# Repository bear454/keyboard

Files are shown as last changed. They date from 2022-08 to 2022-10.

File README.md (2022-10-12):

# keyboard

_**Custom keycaps and layout for my [System76 Launch](https://system76.com/accessories/launch) keyboard**_

Special keys, in a pudding style, for my Launch. These include:

* Caps Lock
* Shift
* Ctrl/Cmd
* Meta/Super/Windows
* Menu
* Alt
* Compose
* Layer 2
* Layer 3
* Enter
* Del
* Bksp
* Home + Play/Pause
* PgUp + Vol Up
* PgDn + Vol Down
* End + Mute

For standard alphanumerics & function keys... just buy yourself some pudding caps. I recommend [LTC's XDA-profile Lava Caps](https://www.amazon.com/LTC-LavaCaps-Translucent-Mechanical-Keyboard/dp/B09J1HMJV9).

## Tools

Keycaps generated using [`openscad`](https://openscad.org/) and [rsheldiii/KeyV2](https://github.com/rsheldiii/KeyV2), then post-processed in [TinkerCAD](https://www.tinkercad.com/things/bIolghDg7ja-keycaps) and sliced in [PrusaSlicer](https://www.prusa3d.com/page/prusaslicer_424/).

Iconography from [Font Awesome 6 Pro](https://fontawesome.com/).

## The current state of things

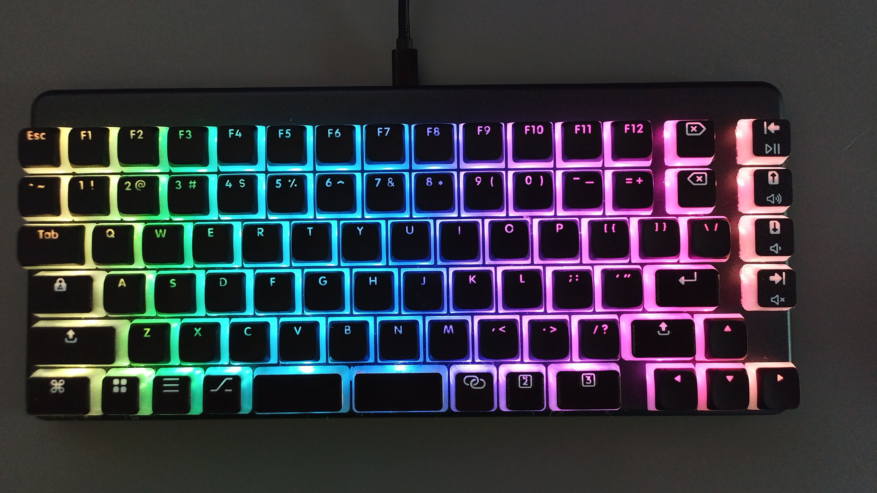
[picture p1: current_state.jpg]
current keyboard layout


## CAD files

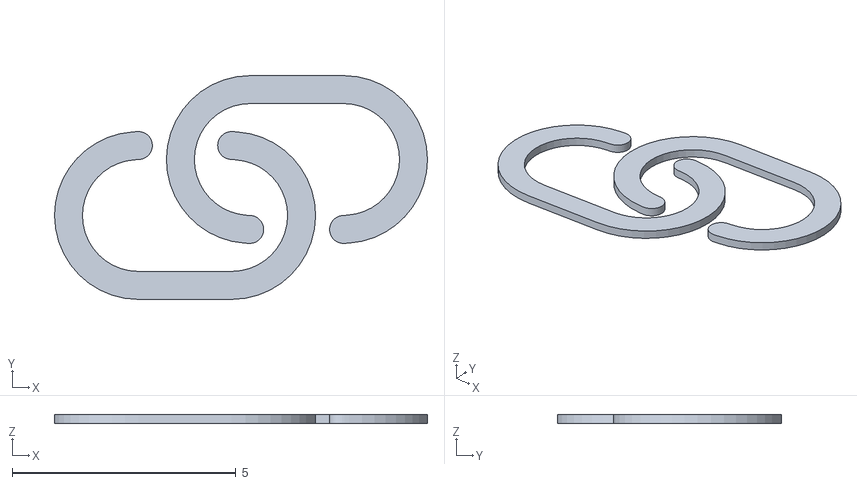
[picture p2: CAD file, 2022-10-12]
print/keycaps-compose-legend.stl
8.33 x 5.00 x 0.2

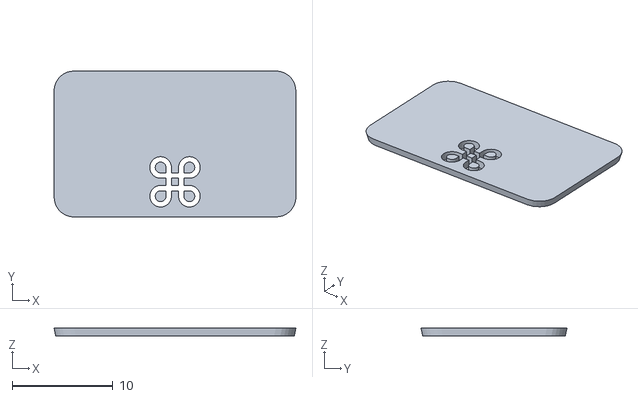
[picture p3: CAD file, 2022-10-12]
print/keycaps-ctrl_1.5u-face.stl
24.0 x 14.5 x 0.798

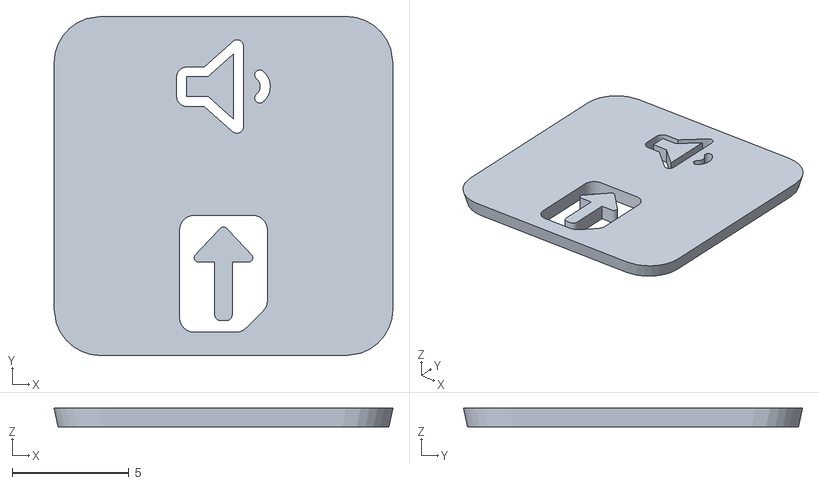
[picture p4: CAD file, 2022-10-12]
print/keycaps-pgdn-face.stl
14.5 x 14.5 x 0.798

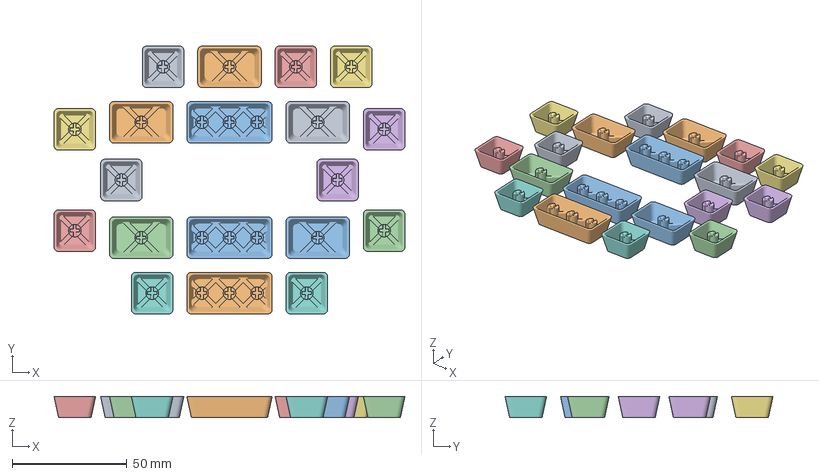
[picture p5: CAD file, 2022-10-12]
print/keycaps.3mf
152.9 x 116.8 x 9.30 mm
compose
caps_1.5u
shift_2u
ctrl_1.5u
window
menu
alt
l2
l3_1.5u
shift_1.5u
enter_1.5u
bksp
del
home
end
pgup
pgdn
space_2u

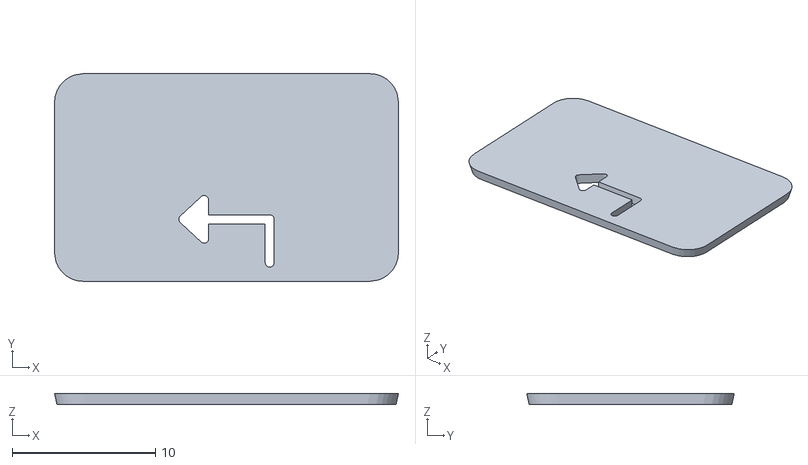
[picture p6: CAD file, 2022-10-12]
print/keycaps-enter_1.5u-face.stl
24.0 x 14.5 x 0.798

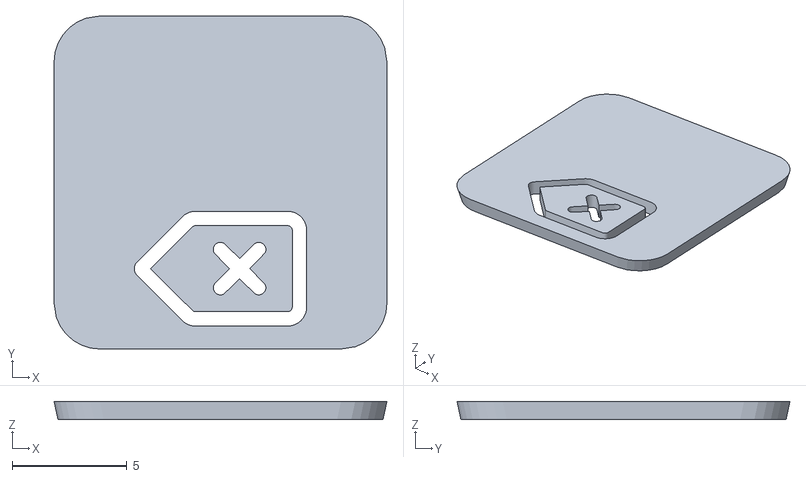
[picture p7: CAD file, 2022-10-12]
print/keycaps-bksp-face.stl
14.5 x 14.5 x 0.798

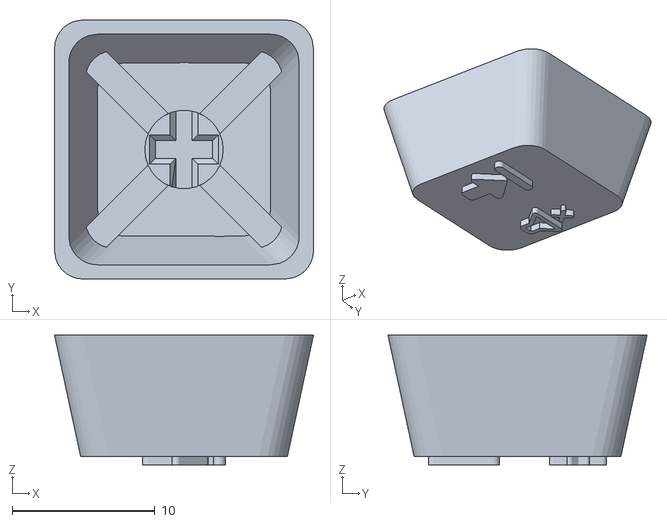
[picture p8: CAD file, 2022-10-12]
print/keycaps-end-body.stl
18.2 x 18.2 x 9.10

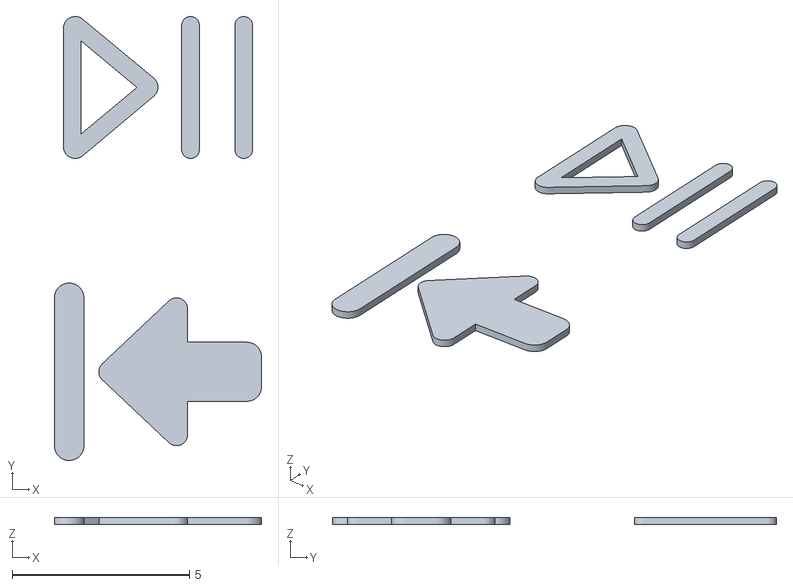
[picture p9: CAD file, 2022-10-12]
print/keycaps-home-legend.stl
5.84 x 12.5 x 0.2

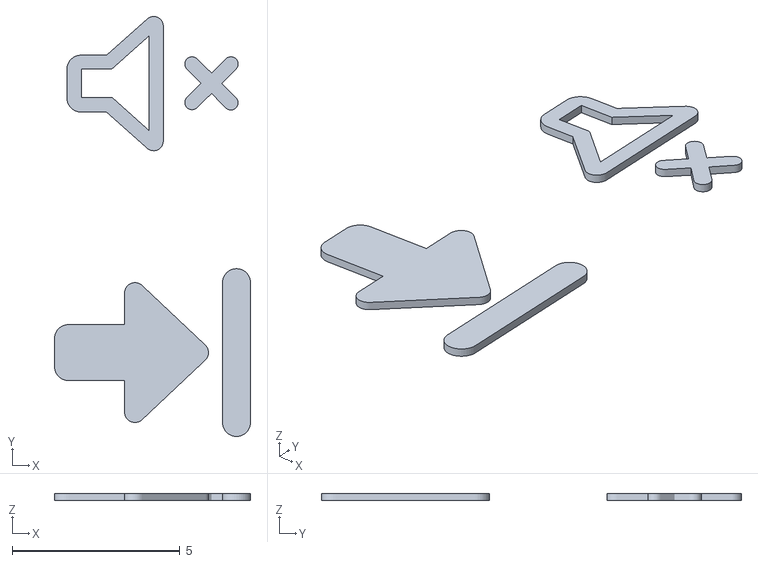
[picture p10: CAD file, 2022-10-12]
print/keycaps-end-legend.stl
5.84 x 12.5 x 0.2

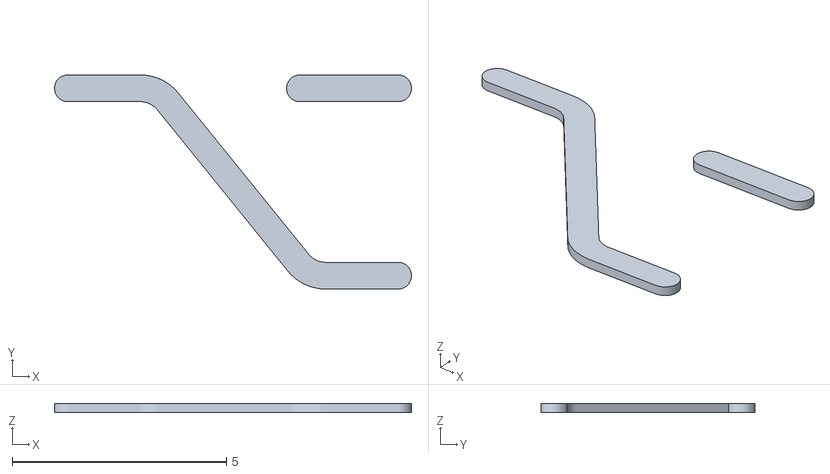
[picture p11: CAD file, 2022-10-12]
print/keycaps-alt-legend.stl
8.33 x 5.00 x 0.2

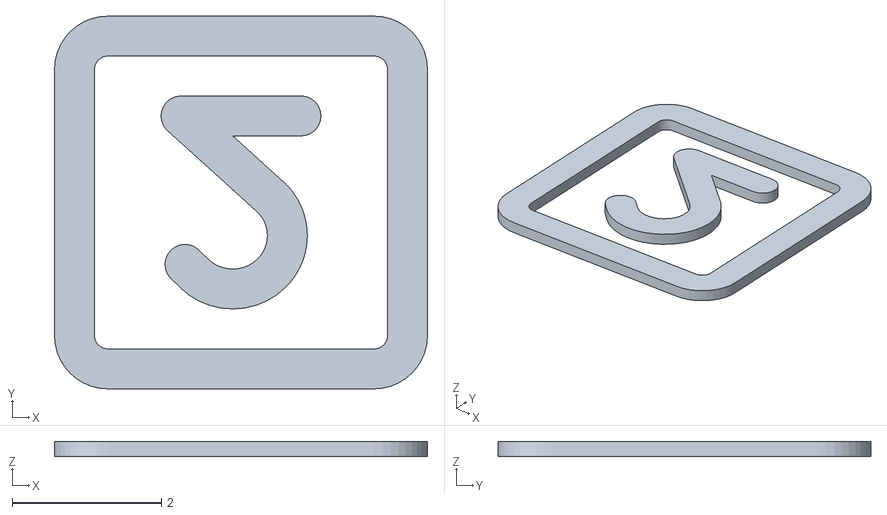
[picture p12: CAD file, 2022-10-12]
print/keycaps-l2-legend.stl
5.00 x 5.00 x 0.2

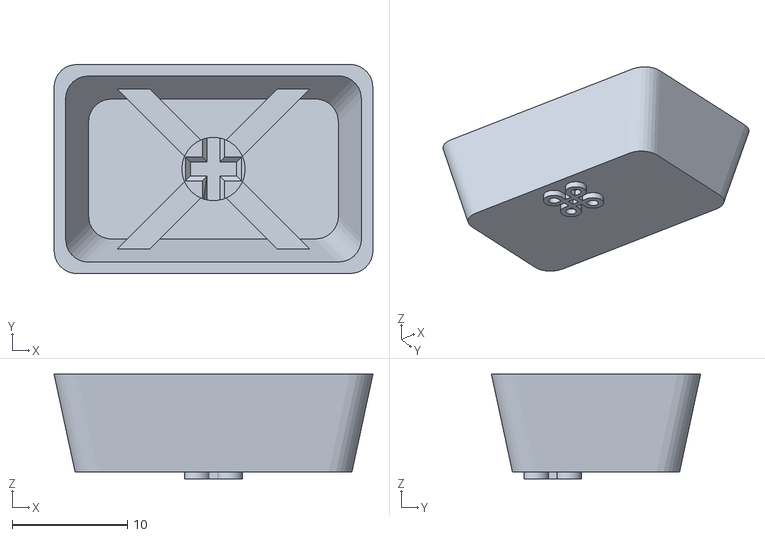
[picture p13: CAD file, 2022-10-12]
print/keycaps-ctrl_1.5u-body.stl
27.7 x 18.2 x 9.10

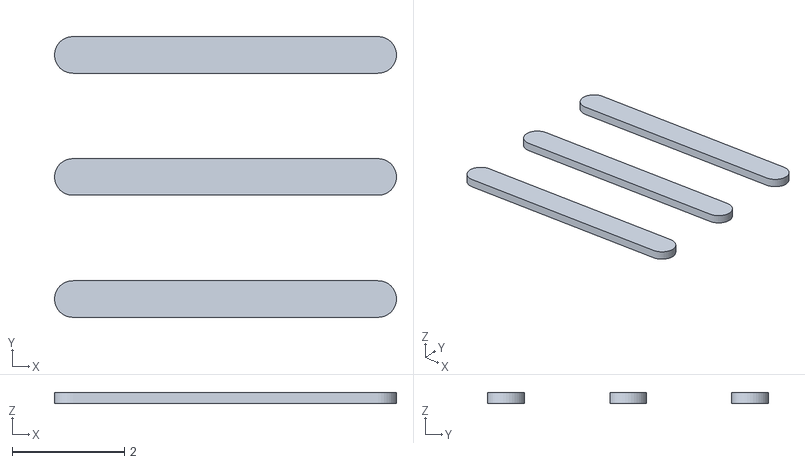
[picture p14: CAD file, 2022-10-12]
print/keycaps-menu-legend.stl
6.09 x 5.00 x 0.2

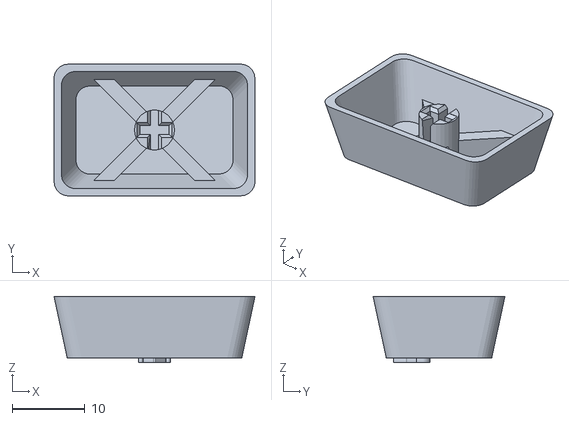
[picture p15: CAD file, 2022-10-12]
print/keycaps-shift_1.5u-body.stl
27.7 x 18.2 x 9.10

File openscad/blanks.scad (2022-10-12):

// load general Launch configs
include <./launch.scad>
// for printing face down
include <./upside_down.scad>

// set the width of key to generate
key_size = 1.0;

if (key_size == 1.0) {
  key();
}

if (key_size == 1.5) {
  1_5u() key();
}

if (key_size == 2.0) {
  $stem_positions = [
    [0,0],
    [-12, 0],
    [12, 0]
  ];
  2u() key();
}

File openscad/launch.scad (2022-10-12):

include <./KeyV2/includes.scad>

//support
$stem_type = "rounded_cherry";
$stabilizer_type = "cherry_stabilizer";
$support_type = "bars";
$stem_slop = 0.05;
$stem_inner_slop = 0.05;

// sizing
$total_depth = 9.3;
$stem_throw = 3.8;
$stem_inset = 1.0;
$keytop_thickness = 0;

// key shape
$top_tilt = 0;
$top_skew = 0;
$width_difference = 4;
$wall_thickness = 2;
$corner_radius = 2;

//legend
$inset_legend_depth = 0.4;

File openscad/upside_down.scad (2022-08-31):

// $stem_slop = 0.1;
$stem_inner_slop = 0;

$dish_type = "disable";
$stem_support_type = "disabled";

//legend
$inset_legend_depth = 0.30;

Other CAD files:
print/keycaps-bksp-body.stl
print/keycaps-home-face.stl
print/keycaps-del-face.stl
print/keycaps-caps_1.5u-legend.stl
print/keycaps-alt-body.stl
print/keycaps-alt-face.stl
print/keycaps-bksp-legend.stl
print/keycaps-caps_1.5u-body.stl
print/keycaps-caps_1.5u-face.stl
print/keycaps-compose-body.stl
print/keycaps-compose-face.stl
print/keycaps-ctrl_1.5u-legend.stl
print/keycaps-del-body.stl
print/keycaps-del-legend.stl
print/keycaps-end-face.stl
print/keycaps-enter_1.5u-body.stl
print/keycaps-enter_1.5u-legend.stl
print/keycaps-home-body.stl
print/keycaps-l2-body.stl
print/keycaps-l2-face.stl
print/keycaps-l3_1.5u-body.stl
print/keycaps-l3_1.5u-face.stl
print/keycaps-l3_1.5u-legend.stl
print/keycaps-menu-body.stl
print/keycaps-menu-face.stl
print/keycaps-pgdn-body.stl
print/keycaps-pgdn-legend.stl
print/keycaps-pgup-body.stl
print/keycaps-pgup-face.stl
print/keycaps-pgup-legend.stl
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

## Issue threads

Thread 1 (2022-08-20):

Layer switch keys should be symmetrical

bear454, 2022-08-20:
Move the 'Layer 2' key out to the left outboard 1.5u key (currently LEFT CTRL) and slide Ctrl, Super & Alt over to the right 1 position.

bear454, 2022-08-22:
Resolved in 0b32246 ... but I don't know if I can get used to it ;-)

Closed 2022-08-22.

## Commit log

2022-08-20 Initial checkin
    [keyV2 - 1.5U Tab Caps Ctrl L3 Shift Enter.stl, keyV2 - 2u Shift.stl, keyV2 - Delete Backspace.stl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]
2022-08-20 Add the Prusaslicer project file
    [Full Set.3mf]
2022-08-20 Add openscad files
    [1.5u.scad, 2u.scad, Del+Bksp.scad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]
2022-08-22 Update layout to use symmetrical layer shifts; shift meta keys over
    [1.5U L2 L3.stl, 1.5u L2 L3.scad, 1.5u Tab Caps Enter rShift.scad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]
2022-08-26 Cleaning up
    [Home+PgUp+PgDn+End.stl, keyV2 - Delete Backspace.stl, keyV2 - Home PgUp PgDn End.stl]
2022-08-31 Cleaning up after finalizing design
    * Square keys instead of rectangles
    * printing upside down on a textured plate
    * flat top instead of dished (necessary for top-down print)
    * no supports required upside-down
    * specifying font per-legend for dual-font legends
    * Tweaked icon sizes for visibily/printability
    [1.5U L2 L3.stl, 1.5u L2 L3.scad, 1.5u Tab Caps Enter rShift.scad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]
2022-10-12 Big update!
    I'm no longer generated the legends via openscad, but doing that as a
    post-process in TinkerCAD, so only generating the blank shapes via
    openscad.
    The blanks have been tweaked to perfection: stem height; overhangs;
    modified enforcers for better legend transparency.
    The faceplate is thicker now, 0.8mm, and I'm doing an actual
    multi-material print instead of colored layering (I didn't likehow the
    material 'drooped' on some of the larger legends... plus this has a more
    consistent 'pudding cup' appearance.
    [1.5u.scad, 1.5u.stl, 2u.scad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]
